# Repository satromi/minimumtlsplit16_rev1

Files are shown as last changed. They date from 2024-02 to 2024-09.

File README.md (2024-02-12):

# minimum TL Split Keyboard 16mm Rev1紹介

## はじめに
minimum TL Split Keyboard 16mm Rev1は、TRON最小化配列のキーボードです。
オリジナルのTRON最小化配列に、TRON配列にあるカーソルキーを左右に加えることで使いやすくしています。
TRON最小化配列の16mmピッチを、Cherry MXキーで実現しています。

## 配列
72キーなので、ファンクションキーやテンキーは、"TG"キーでファンクション面に切替えて使います。
入門しやすさを重視し、QWERTY配列としています。要望があれば、DVORAK配列やTRON配列も定義します。
- QWERTY配列面

~~~
        ,-----------------------------------------.              ,-----------------------------------------.
        |   [  |   1  |   2  |   3  |   4  |   5  |              |   6  |   7  |   8  |   9  |   0  |   -  |
 ,------+------+------+------+------+------+------+------.,------+------+------+------+------+------+------+------.
 |  ESC | CTRL |   Q  |   W  |   E  |   R  |   T  |  DEL ||  INS |   Y  |   U  |   I  |   O  |   P  |   @  | YEN| |
 |------+------+------+------+------+------+------+------||------+------+------+------+------+------+------+------|
 |  HNK |  ALT |   A  |   S  |   D  |   F  |   G  |  TAB ||  ENT |   H  |   J  |   K  |   L  |   ;  |   :  |   ~  |
 `------+------+------+------+------+------+------+------'`------+------+------+------+------+------+------+------'
        |   ]  |   Z  |   X  |   C  |   V  |   B  |              |   N  |   M  |   ,  |   .  |   /  |   \  |
        `-----------------------------------------'              `-----------------------------------------'
               ,------.      ,---------------------------.,---------------------------.      ,------.
               | PGUP |      |  SPC |  SFT |   TG |  CPS ||   JP | MUTE |  SFT |  BSP |      |   UP |
        +------+------+------+---------------------------'`---------------------------+------+------+------+
        | HOME | PGDN |  END |                                                        |  LFT |  DWN |  RGT |
        `--------------------'                                                        `--------------------'
~~~

- ファンクション面

ファンクション面の空白箇所は、キー割り当てがありません。

~~~
        ,-----------------------------------------.              ,-----------------------------------------.
        |      |   F1 |   F2 |   F3 |   F4 |   F5 |              |   F6 |   F7 |   F8 |   F9 |  F10 |    * |
 ,------+------+------+------+------+------+------+------.,------+------+------+------+------+------+------+------.
 |  ESC | CTRL |      |      |      |      |      |  DEL ||    = |    . |    7 |    8 |    9 |    / |    - |  F11 |
 |------+------+------+------+------+------+------+------||------+------+------+------+------+------+------+------|
 |  HNK |  ALT |      |      |      |      |      |  TAB ||  ENT |    , |    4 |    5 |    6 |    * |NUMLOC|  F12 |
 `------+------+------+------+------+------+------+------'`------+------+------+------+------+------+------+------'
        |      |      |      |      |      |      |              |    0 |    1 |    2 |    3 |    + |      |
        `-----------------------------------------'              `-----------------------------------------'
               ,------.      ,---------------------------.,---------------------------.      ,------.
               | PGUP |      |  SPC |  SFT |   TG |  CPS ||   JP | MUTE |  SFT |  BSP |      |   UP |
        +------+------+------+---------------------------'`---------------------------+------+------+------+
        | HOME | PGDN |  END |                                                        |  LFT |  DWN |  RGT |
        `--------------------'                                                        `--------------------'
~~~

## ビルドガイド
ビルドガイドは、[buildguide.md](https://github.com/satromi/minimumtlsplit16_rev1/blob/master/buildguide.md) を参照してください。

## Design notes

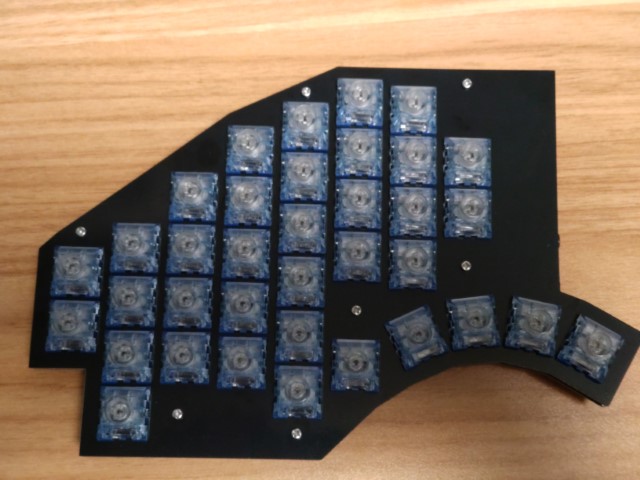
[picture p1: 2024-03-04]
image/key.jpg

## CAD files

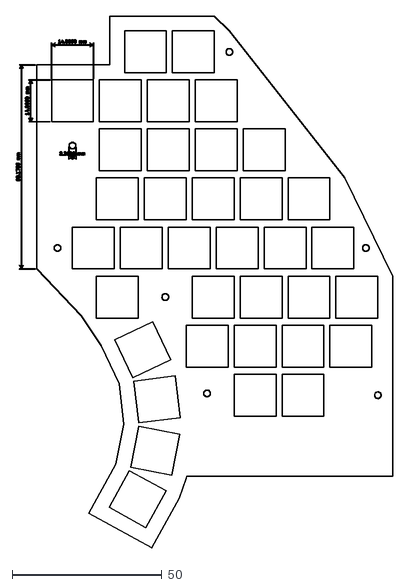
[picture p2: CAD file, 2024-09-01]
dxf/minimum_tlsplit16mm_topplate-Edge_Cuts.dxf
125.8 x 177.7

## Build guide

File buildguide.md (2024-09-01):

# minimum TL Split Keyboard 16mm Rev1ビルドガイド

minimum TL Split Keyboard 16mm Rev1は、TRON最小化配列のキーボードです。
TRON最小化配列の16mmピッチを、Cherry MXキーで実現しています。

## 説明
minimum TL Split Keyboard 16mm Rev1は、PCBが左右違います。4.7kΩ抵抗（R1,R2）がある方が左です。
基本的に、左側にUSBケーブルを接続するようにしています。

PCBには、表面と裏面があります。"minimum TL Split Keyboard"と記載がある方が、裏面です。

## 組み立て
### PCBへパーツ半田付け

- ダイオードを、左右PCB裏面に36カ所実装します。

ダイオードを、左右PCB裏面に実装します。ダイオードは極性があるので、カソード（黒い方）をシルク印刷で線が入っている方（かつKと書かれて、穴が四角の方）になるよう、左右それぞれ36カ所半田付けしていきます。

- 4.7kΩ抵抗を左側PCB表面に2カ所実装します。

4.7kΩ抵抗を、左側PCB表面のみに実装します。極性は無いので、どちらでもかまいません。

- リセットスイッチを、左右PCB裏面に実装します。

リセットスイッチを、左右PCB裏面に実装します。左右PCBそれぞれに1カ所ずつリセットスイッチ位置があるので、半田付けしてください。

※裏面にシルク印刷されています。

- TRRSジャックを、左右PCB裏面に実装します。

TRRSジャックを、左右PCB裏面に実装します。左右PCBに、それぞれ半田付けしてください。

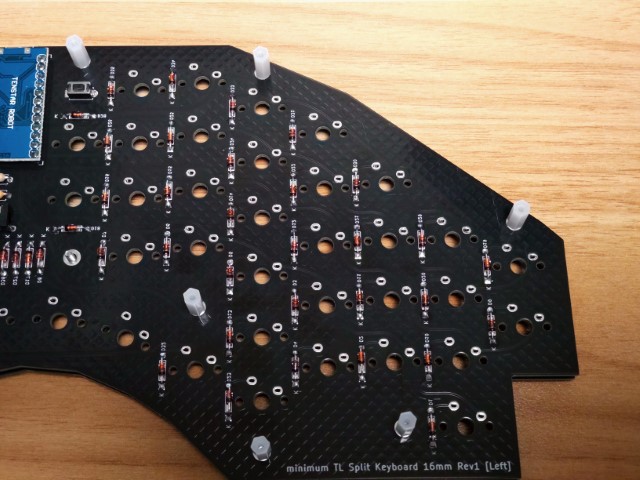
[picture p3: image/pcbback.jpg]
パーツ半田付け


※裏面にシルク印刷されています。

### Pro Microへコンスルー半田付け

遊舎工房で購入すれば、コンスルー付きが買えます。

PCBから外した状態で、部品（USBコネクタなど）が実装されている面にコンスルーを載せて、半田付けします。

できたら、左右PCBの裏面にはめ込みます。基板の外側（左側は左、右側は右）にUSBコネクタが来るようにはめます。

### CherryMX キースイッチ半田付け

トッププレートとPCBの間に短い方のスペーサー(3mm)をはさみ、左右それぞれ7カ所を長い方のねじ（10mm）でネジ止めします。ねじ頭が上側に来るようにして、PCBの下には長い方のスペーサー(6.5mm)で止めてください。
キースイッチをトッププレートの上からトッププレート・PCBにはめ込み、固定します。ここでキーが浮かないよう、しっかりトッププレートにはめ込んで、半田付けしてください。

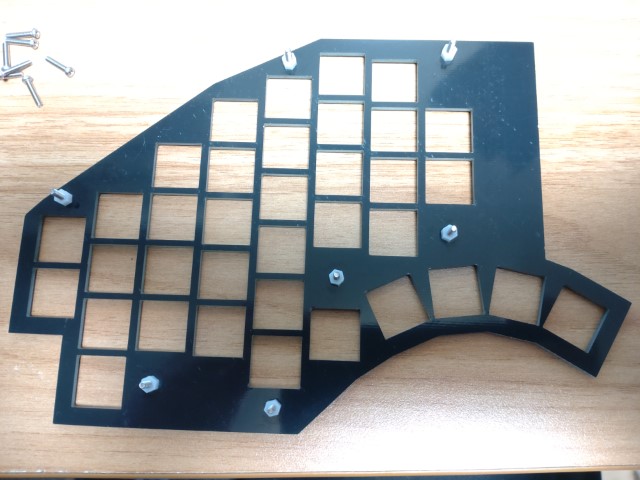
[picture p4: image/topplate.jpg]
トッププレート


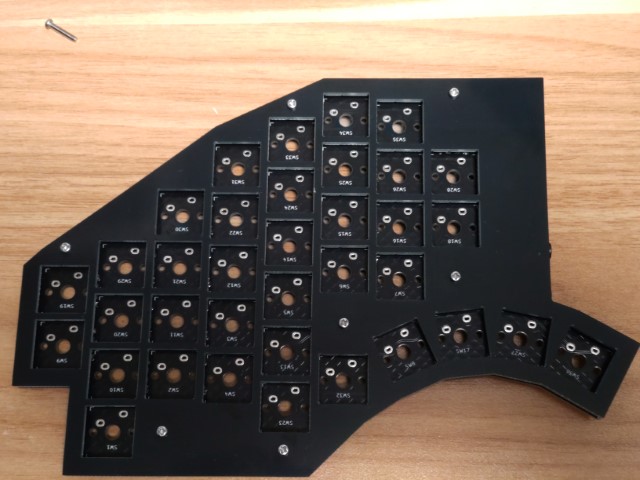
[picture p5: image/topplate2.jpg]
トッププレート2


CherryMXキースイッチは、親指扇形部分含め72カ所半田付けします。

※注意点:親指キー部分は、キースイッチによっては干渉してしまう場合があります。その場合、干渉するキーの出っ張り部分をニッパ等で切り落としてください。

## ProMicroにファームウェア書き込み
[QMK Toolbox](https://github.com/qmk/qmk_toolbox) で、ファームウェア（hexファイル）をProMicroに書き込む必要があります。

[QMK Toolbox](https://github.com/qmk/qmk_toolbox) のインストール・使い方については、サリチル酸さんが書かれた[（初心者編）自作キーボードにファームウェアを書き込む](https://salicylic-acid3.hatenablog.com/entry/qmk-toolbox) が分かりやすいです。

minimum TL Split Keyboardのファームウエアは、 [satromi_mintlsplit_default.hex](https://github.com/satromi/minimumtlsplit16_rev1/blob/main/hex/satromi_mintlsplit_default.hex) をダウンロードしてQMK Toolboxで書き込みます。

ファームウェアは、左右のProMicroそれぞれに書き込む必要があります。

Dvorak配列のファームも公開しています。[satromi_mintlsplit_dvorak.hex](https://github.com/satromi/minimumtlsplit16_rev1/blob/main/hex/satromi_mintlsplit_dvorak.hex) をダウンロードして、QMK Toolboxで書き込みます。

他のキーマップに変更したい場合は、VIA対応ファームウェアも準備しています。[satromi_mintlsplit_via.hex](https://github.com/satromi/minimumtlsplit16_rev1/blob/main/hex/satromi_mintlsplit_via.hex) をダウンロードして、QMK Toolboxで書き込みます。

VIA対応ファームウェアの場合、Webサイトからキーマップを変更できる [REMAP](https://remap-keys.app/)  も利用できます。
[REMAPのminimum TL Split Keyboardページ](https://remap-keys.app/catalog/6Lzaoh8tO5NVf4gDDHTs)  から書き換えてみてください。

## 動作確認

左右のキーボードをTRRSケーブルで繋いだら、USBケーブルでPCと接続し、動作確認してください。

## ボトムケース取り付け

動作確認して問題なければ、ボトムプレートを取り付けます。左右それぞれ7カ所を短い方のねじ（6mm）でネジ止めします。ねじ頭が下側（ボトムケース側）に来るようにしてください。

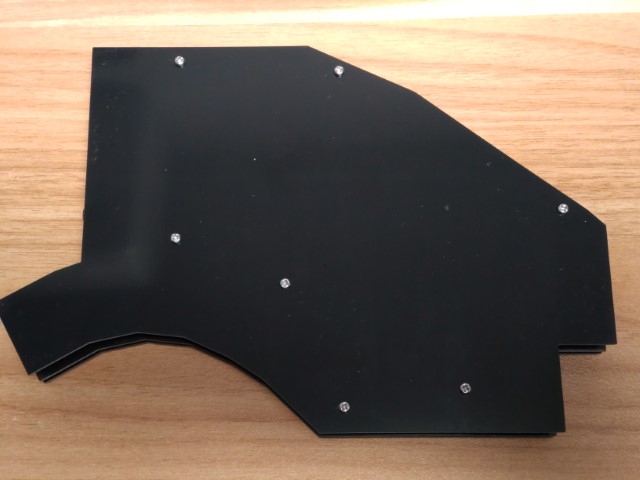
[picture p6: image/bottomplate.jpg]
ボトムプレート取り付け


最後に、クッションゴムを取り付けます。左右それぞれ6カ所貼り付けます。お好きな位置に取り付けてください。

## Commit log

2024-02-12 説明アップ
2024-02-18 hexファイル追加
2024-02-18 buildguide.md修正
2024-02-18 buildguide.md再修正
2024-02-18 buildguide.mdパス修正
2024-02-23 via用のfunctionバグを修正
2024-03-04 ネジ本数修正
2024-03-04 buildguide.md URL修正
2024-09-01 dxfファイル追加
    [minimum_tlsplit16mm_topplate-Edge_Cuts.dxf]
